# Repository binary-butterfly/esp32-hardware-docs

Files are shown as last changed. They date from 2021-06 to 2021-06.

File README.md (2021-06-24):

# Universelle ESP32 Steuerungs-Platine 

Die ESP32 Steuerungs-Platine wurde als Hardware zum MicroPython-basierten [Open Booking Client](https://github.com/binary-butterfly/open-booking-client-esp32) entwickelt. Sie eignet sich aber für eine ganze Reihe anderer Anwendungen.

# Urheberschaft / Lizenz

Das Platinenlayout wurde von der [TUG Herrenberg](https://tug-herrenberg.de) entwickelt, Dokumentation und Software stammen von der [binary butterfly GmbH](https://binary-butterfly.de). Die Platine wurde im Rahmen des Förderprojektes [stadtnavi](https://stadtnavi.de) entwickelt.

Alle Daten im Repository stehen unter der [Creative Commons BY](https://creativecommons.org/licenses/by/4.0/).

# Dokumentation

* [Setup](./docs/setup.md)
* [Materialliste](./docs/hardware.md)
* [Board-Herstellung](./docs/production.md)

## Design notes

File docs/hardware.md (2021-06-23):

# Hardware

## Platine

* 1x Platine, Epoxyd, doppelseitig, 160 x 100 mm - wenn man diese selbst fräsen / ätzen will
* 1x NodeMCU ESP32
* 2x Elko radial, 1.500µF, 16V
* 10x Anschlussklemme, 2-pol, RM 5,08 mm, 90°
* 1x Präzisionsfassung, 16 polig, RM 2,54
* 1x Präzisionsfassung, 18 polig, RM 2,54  
* 1x 4-fach Optokoppler, 5kV, 35V, 50mA, 50-600%, DIP-16
* 1x Leistungstreiber, 8-Kanal, DIL-18
* 1x DC/DC-Wandler, 2 W, 5 V, SIL 4
* 6x Widerstand 1,1 kOhm

## Weitere Komponenten je nach Anwendung

* Montagesockel für Europlatinen: damit lässt sich die Platine auf eine Hutschine montieren
* Schaltnetzteil, Hutschiene, 19 W, 12 V, 1,6 A: eine zuverlässige Stromversorgung für die Hutschiene
* Relaismodul Push-In, 1 Schließer, 12 V DC: ein Relais-Modul für die Hutschiene
* Magnetschalter: Erkennung, ob die Tür offen oder geschlossen ist  
* HMIP DLD Türschlossantrieb: eine Consumer-Türschloss-Steuerung, dessen Fernbedienung man mit einem Relais steuern kann
* Simons&Voss MobileKey: ein professionelles Türschloss-System, welches sich mit einem Schalttransponder fernsteuern lässt
* ABUS Mechanischer Türöffner MT90 oder ein beliebiger anderer Türsummer:   
* TTL232 UHF RFID: ein via UART anschließbares UHF-RFID-Modul, mit dem man auf bis zu mehreren Metern Entfernung Tags erkennen kann
* Adafruit PN532: ein DIY-RFID-Reader mit sehr gutem Empfang
* ELATEC TWN4: ein professioneller RFID-Reader

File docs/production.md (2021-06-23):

# Platine herstellen

## CNC Fräse

Um die Platine herzustellen muss sind im Ordner `/board/` drei TAP-Dateien, um die Fräse anzusteuern:

* die `/board/rad.bot.etch.tap` beschreibt das Wegfräsen auf der Unterseite
* die `/board/rad.top.etch.tap` beschreibt das Wegfräsen auf der Oberseite  
* die `/board/rad.bot.drill.tap` beschreibt die Bohrlöcher

## Professionelle Dienstleister

Hat man keine CNC-Fräse zur Hand, so lohnt ein Blick auf professionelle Anbieter, welche einem printed circuit boards (PCBs) herstellen. Herstellungskosten für das Board liegen bei ca. 10 - 20 Euro. Hersteller von PCBs erwarten ein Layout, welches in `/board/board.kicad_pcb` als KiCad-Datei vorliegt.

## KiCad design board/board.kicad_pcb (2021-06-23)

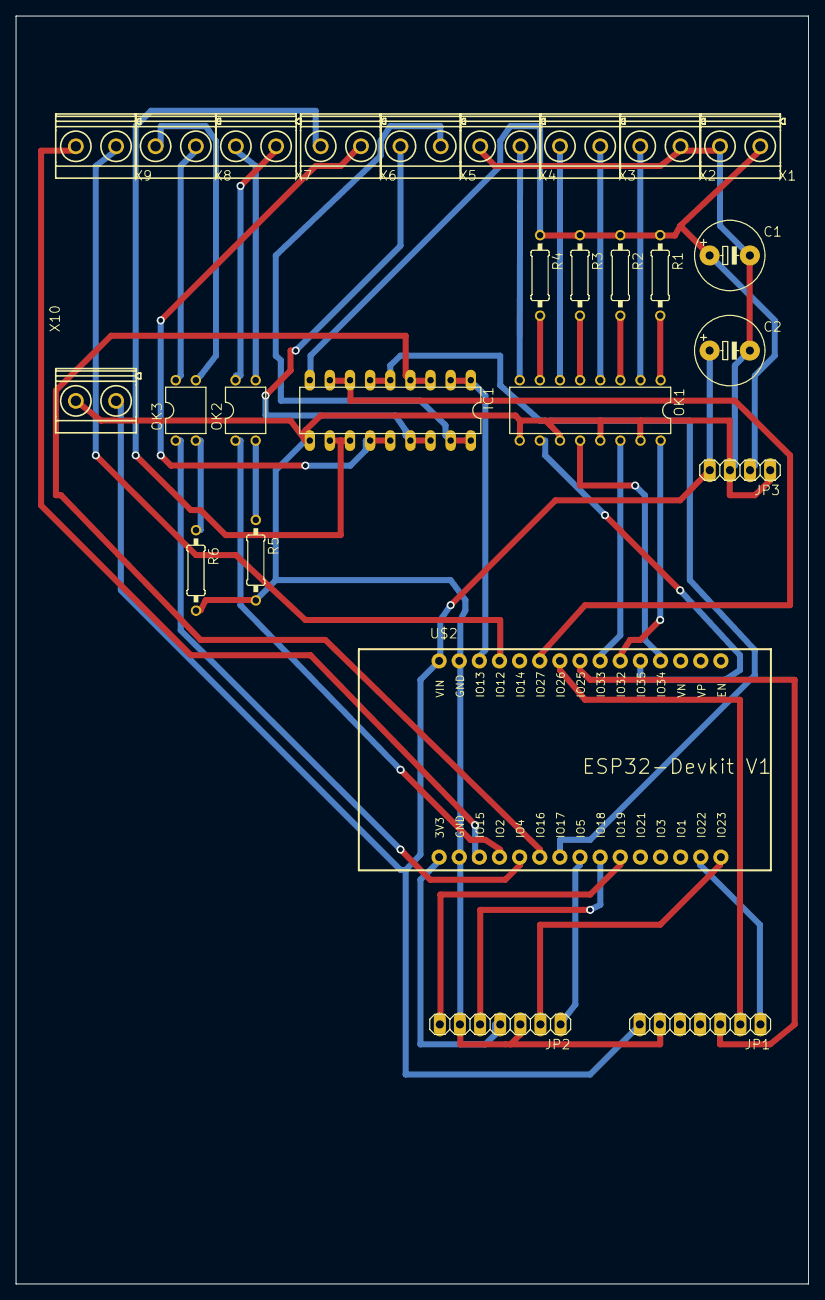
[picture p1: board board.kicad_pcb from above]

Board: 2 copper layers, 100.0 x 160.0 mm, 26 parts (0 on the bottom side), 41 nets.

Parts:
C1, C2: CPOL-EUE5-8.5; E5-8,5
IC1: UDN298A; DIL18
JP1, JP2: PINHD-1X7; 1X07
JP3: PINHD-1X4; 1X04
OK1: PC847; DIL16
OK2, OK3: PC817; DIL04
R1, R2, R3, R4, R5, R6: R-EU_0207_10; 0207_10
U$2: ESP32-DEVKITV1_ESP32DEVKITV1; ESP32-DEVKITV1_ESP32-DEVKITV1
X1, X2, X3, X4, X5, X6, X7, X8, X9, X10: MKDSN1,5_2-5,08

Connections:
/2: OK2.1, U$2.4
/3V: JP2.4, U$2.1
/4: OK3.1, U$2.5
/5V: C2.+, JP1.7, JP3.4, U$2.30, X10.1
/12V: C1.+, IC1.9, JP3.2, R1.1, R2.1, R3.1, R4.1, X1.1
/13: IC1.1, IC1.2, U$2.28
/16: IC1.3, IC1.4, U$2.6
/17: IC1.5, IC1.6, U$2.7
/27: IC1.7, IC1.8, U$2.25
/32: OK1.16, U$2.21
/33: OK1.14, U$2.22
/34: OK1.12, U$2.19
/35: OK1.10, U$2.20
/BCLK: JP1.2, U$2.24
/DIN: JP1.3, U$2.23
/GND: C1.-, C2.-, IC1.10, JP1.6, JP2.3, JP2.6, JP3.1, JP3.3, OK1.9, OK1.11, OK1.13, OK1.15, R5.2, R6.2, U$2.2, U$2.29, X1.2, X2.1, X4.2, X10.2
/LRC: JP1.1, U$2.14
/MISO: JP2.7, U$2.10
/MOSI: JP2.2, U$2.15
/RXD3: U$2.3, X9.2
/SCK: JP2.5, U$2.9
/SS: JP2.1, U$2.8
/TXD3: U$2.27, X9.1
unnamed: IC1.11, IC1.12, X6.2
unnamed: IC1.13, IC1.14, X6.1
unnamed: IC1.15, IC1.16, X5.2
unnamed: IC1.17, IC1.18, X5.1
unnamed: OK1.1, R1.2
unnamed: OK1.2, X2.2
unnamed: OK1.3, R2.2
unnamed: OK1.4, X3.1
unnamed: OK1.5, R3.2
unnamed: OK1.6, X3.2
unnamed: OK1.7, R4.2
unnamed: OK1.8, X4.1
unnamed: OK2.2, R5.1
unnamed: OK2.3, X7.2
unnamed: OK2.4, X7.1
unnamed: OK3.2, R6.1
unnamed: OK3.3, X8.2
unnamed: OK3.4, X8.1

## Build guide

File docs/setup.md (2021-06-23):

# Setup

Die Platine ermöglicht es, vier normale Eingänge und vier normale Ausgänge zu nutzen. Im Fall des Cargobike-Schließ-Systems gibt es folgende Geräte:

* Tür-Sensor (Eingang)
* Tür-Schloss öffnen (Ausgang)
* Tür-Schloss schließen (nur Consumer-Schloss, Ausgang)
* Tür-Summer: Ausgang

Beim Consumer-Schloss wird die Fernbedienung des Schlosses so umgebaut, dass öffnen und schließen an den beiden Ausgängen angeschlossen sind. 

Außerdem gibt es noch UART, um z.B. folgende Komponenten anzuschließen:

* UHF-RFID-Reader
* ELATEC RFID Reader

Ebenso SPI:

* Adafruit ESP23
